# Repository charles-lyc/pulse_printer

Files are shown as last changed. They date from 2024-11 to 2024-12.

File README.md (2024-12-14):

# pulse_printer

## Introduce

2024 Maker Fair的小作品，放在SZDIY社区下面展出。观众可以将手指按压在指定位置十秒钟，即可得到机器为你量身打造的粗略心率曲线图，并且会有相应的小动物代表心率水平 ;-)

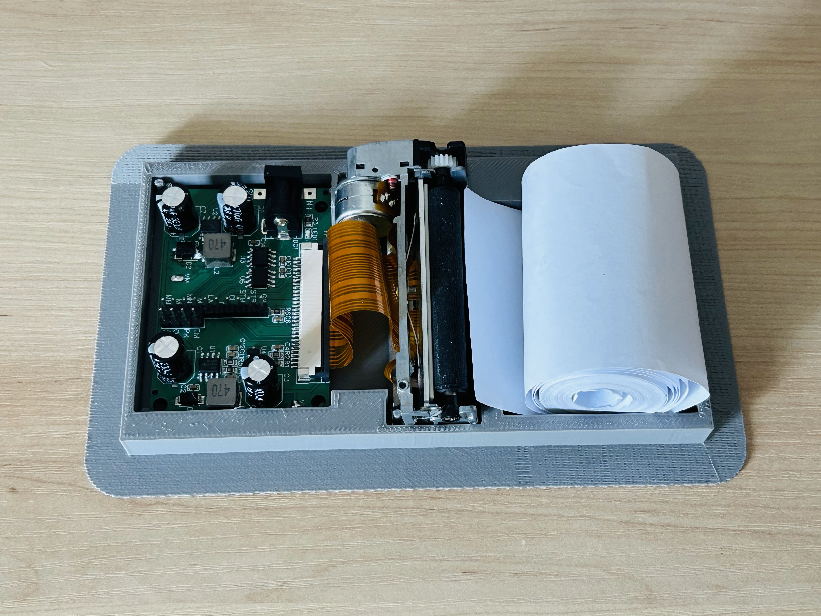
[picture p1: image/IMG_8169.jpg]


## Detail

* 获取心跳/脉搏信号：测量原理是检测血氧浓度（对不同波长光的吸收率不同）。可以使用**MAX30102**，我当时买错了将就用一下，ADC直出

* 热敏打印：打印纸局部加热后，发生化学反应（显色反应）

* 热敏打印的驱动：我在淘宝买的打印头和驱动板。驱动板主要就是电源，打印头里面应该是有个小芯片，原理类似于串转并芯片。打印过程其实就是逐行把像素点描黑或留白。为了一行打印，就需要利用DI、CLK和LAT锁存，将一行的像素缓存至打印机驱动小芯片里（输入一行结束，锁存拉高，等FLUSH完成，步进电机移动一行）。

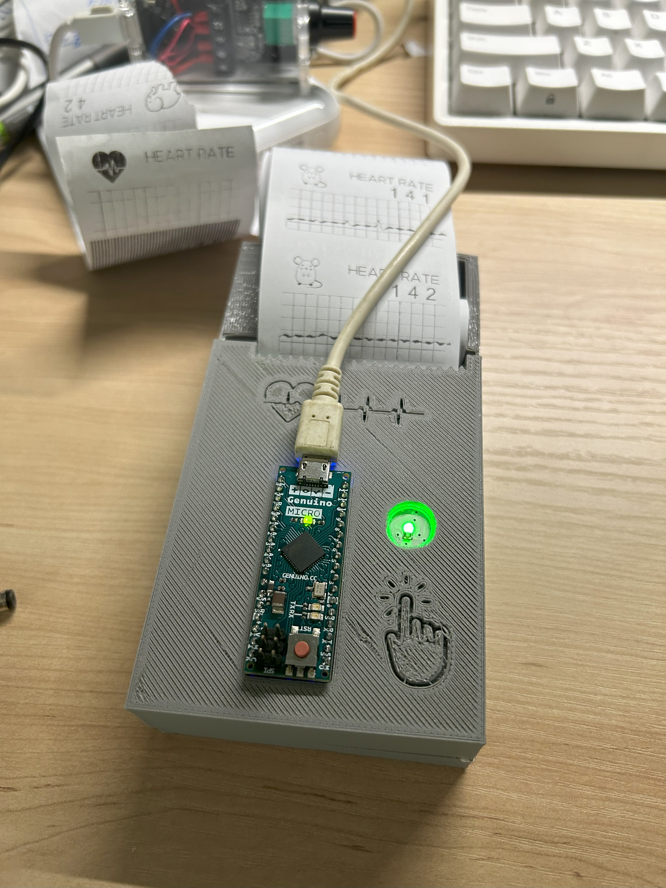
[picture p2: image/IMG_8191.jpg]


## TODO

* 控制脉搏传感器的电源，没有人按下时不要开（指纹底下应设计个按钮）

* 第二版还可以加入多人联机，然后测同步率，用一个彩屏来显示曲线相位...（但我估计懒得搞）

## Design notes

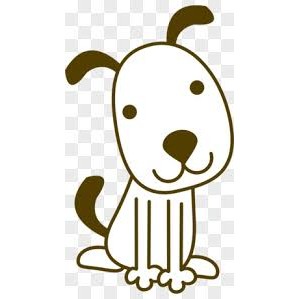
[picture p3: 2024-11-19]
misc/ui/d.jpg

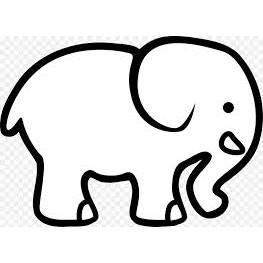
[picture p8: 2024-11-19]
misc/ui/e.jpg

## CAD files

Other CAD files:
shell/Pulse Printer v23.f3d

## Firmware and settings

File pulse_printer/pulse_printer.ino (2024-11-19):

#include "./HPD482.h"          //打印机头文件
#include "./img_background.h"  //待打印的图片数据
#include "./font.h"            //待打印的图片数据

#define BUFFER_SZ 1000
#define DISP_SZ 376
#define minADC 300
#define maxADC 800
#define WIDTH 384
#define HEIGHT 240
#define ANIM_X 16
#define ANIM_Y 8
#define DIGIT_X 0
#define DIGIT_Y 60
#define CURVE_X 8
#define CURVE_Y 105
HPD482 printer = HPD482();
const int btn_start_once = 22;
const int btn_empty = 18;
const int led = 13;
u8 hram[48], last_hram[48];
float alpha = 0.9;
u8 heart_rate_value[BUFFER_SZ];
bool start_once = false;
bool press_even = false;

// 统计大于均值线的独立区域的个数
int countPeaks(u8 *data, int size, int mean_line) {
  int peakCount = 0;
  int isAboveMean = 0;  // 标记是否在均值线以上
  u8 *pdata = (u8 *)data;

#if 0
	for (int i = 0; i < size; i++) {
		*pdata++ = *praw++;
	}
#endif
  // 遍历信号数组
  for (int i = 0; i < size; i++) {
    // 当前点高于均值线，且之前不在波峰中
    if (data[i] > mean_line && !isAboveMean) {
      isAboveMean = 1;
      peakCount++;  // 发现新的波峰，计数加1
    }
    // 当前点低于或等于均值线
    else if (data[i] <= mean_line) {
      isAboveMean = 0;  // 重置标记
    }
  }

  return peakCount;
}

void setup() {
  Serial.begin(9600);
  printer.Print_SetDeep(8);
  pinMode(btn_start_once, INPUT_PULLUP);
  pinMode(btn_empty, INPUT);
  pinMode(led, OUTPUT);
  randomSeed(analogRead(0));
}

void loop() {
BEGIN:
  int adcValue = 0;
  static int last_adcValue = 0;
  int bpm = 0;
  int mean = 0;
  long sum = 0;
  int region_count = 0;
  u8 *p_value;
  int count = 0;

  // 读取心率数据并处理
  memset(heart_rate_value, 0, sizeof(heart_rate_value));
  for (int i = 0; i < BUFFER_SZ; i++) {
    adcValue = analogRead(A5);
    // Serial.print(adcValue);
    // Serial.print(',');
    adcValue = alpha * adcValue + (1 - alpha) * last_adcValue;
    last_adcValue = adcValue;
    if (adcValue > maxADC) {
      adcValue = maxADC;
    }
    if (adcValue < minADC) {
      adcValue = minADC;
    }
    adcValue = (float)(adcValue - minADC) / (float)(maxADC - minADC) * 129.0f;

    // 等待第一个异常值作为开始，优信这款adc心率计在手指刚放上去时有明显的波动和异常值（糊弄）
    if (adcValue < 5) {
      Serial.println("press_even");
      press_even = true;
      digitalWrite(led, LOW);
      goto BEGIN;
    } else {
      if (press_even) {
        press_even = false;
        start_once = true;

        Serial.println("start_once");

        digitalWrite(led, HIGH);
        delay(50);
        digitalWrite(led, LOW);
        delay(50);
      }
      digitalWrite(led, HIGH);
    }

    // 环境也有数值
    if (!start_once) {
      goto BEGIN;
    }

    Serial.println(adcValue);
    heart_rate_value[i] = adcValue;
    delay(9);  // 孱弱的机能
  }
  start_once = false;

  Serial.println("Start process...");

  // 当按下达到8s，开始计算并打印心率和曲线
  for (int i = 0; i < BUFFER_SZ; i++) {
    sum += heart_rate_value[i];
  }
  mean = sum / BUFFER_SZ;
  mean += 8;
  Serial.println(mean);
  region_count = countPeaks(heart_rate_value, BUFFER_SZ, mean);
  Serial.println(region_count);
  bpm = region_count * 60.0 / (BUFFER_SZ / 100);
  Serial.println(bpm);
  if (bpm < 45) {
    bpm = 45;
  }
  if (bpm > 180) {
    bpm = 180;
  }
  if (bpm == 45 || bpm == 180) {
    Serial.println("Ramdon");
    bpm = random(50, 160);
    Serial.println(bpm);
  }

  // 将所有需要打印的图片都缓存到hram中，一行行计算
  memset(last_hram, 0x00, sizeof(hram));
  for (int row = 0; row < HEIGHT; row++) {
    memset(hram, 0x00, sizeof(hram));

    // 背景
    for (int i = 0; i < sizeof(hram); i++) {
      hram[i] = pgm_read_byte(&gPic_background[row * (WIDTH / 8) + i]);
    }

    // 动物标志
    const unsigned char *p = gPic_dog;
    if (row >= ANIM_Y && row < ANIM_Y + 96) {
      int line = (row - ANIM_Y);
      if (bpm < 60) {
        p = gPic_Elephant;
      } else if (bpm < 110) {
        p = gPic_dog;
      } else {
        p = gPic_mouse;
      }
      for (int i = 0; i < 96 / 8; i++) {
        hram[ANIM_X / 8 + i] = pgm_read_byte(&p[line * (96 / 8) + i]);
      }
    }

    // // 数字
    if (row >= DIGIT_Y && row < DIGIT_Y + 40) {
      u8 digit_1 = bpm / 100;
      u8 digit_2 = (bpm % 100) / 10;
      u8 digit_3 = bpm % 10;
      for (int i = 0; i < sizeof(hram); i++) {
        for (int i = 0; i < 40 / 8; i++) {
          if (digit_1 != 0) {
            hram[30 + (40 / 8) * 0 + i] = pgm_read_byte(&ascii_pic4040[digit_1][(row - DIGIT_Y) * (40 / 8) + i]);
          }
          hram[30 + (40 / 8) * 1 + i] = pgm_read_byte(&ascii_pic4040[digit_2][(row - DIGIT_Y) * (40 / 8) + i]);
          hram[30 + (40 / 8) * 2 + i] = pgm_read_byte(&ascii_pic4040[digit_3][(row - DIGIT_Y) * (40 / 8) + i]);
        }
      }
    }

    // 曲线
    if (row >= CURVE_Y && row < CURVE_Y + 130) {
      int line = (129 - (row - CURVE_Y));
      // Serial.print(line);

      // 简易加粗（复制上一次）
      for (int i = 0; i < 48; i++) {
        // hram[i] |= last_hram[i];
      }
      memset(last_hram, 0x00, sizeof(hram));

      // 遍历心率数据，只要两点间连线出现在当前行就应标记为1
      for (int t = 1; t < DISP_SZ; t++) {
        p_value = heart_rate_value;
        // i等于当前像素，标记hram为1
        // i-1的值小于当前hram的行位置像素，i大于等于当前像素，标记hram为1
        // i-1的值大于当前hram的行位置像素，i小于等于当前像素，标记hram为1
        if ((p_value[t] == line) || (p_value[t - 1] < line && p_value[t] > line) || (p_value[t - 1] > line && p_value[t] < line)) {
          hram[(CURVE_X / 8) + (t / 8)] |= 0x01 << (7 - t % 8);
          last_hram[(CURVE_X / 8) + (t / 8)] |= 0x01 << (7 - t % 8);
        }
      }
    }

    // 逐行绘画
    printer.Print_Picture(0, hram, WIDTH, 1, 0);
  }

  printer.Motor_Run(70, 0);
  printer.Print_Stop();
}

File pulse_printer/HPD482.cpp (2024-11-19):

/*
HPD482驱动程序v3.6 for Arduino UNO
///////////////////////////////////////////////////////////////////////////////////////////////
作者：有立diy
淘宝店铺：有立diy
淘宝链接：https://shop587795831.taobao.com/
原创声明：本例程为热敏打印机模块HPD482配套例程，仅供参考，不得用于商业等用途，其他后果概不负责。
		  如需使用，注明出处。
///////////////////////////////////////////////////////////////////////////////////////////////
*/
#include "HPD482.h"
#include "font.h"

//打印机微秒延时
void HPD482::pdelay_us(u16 tus)
{
	delayMicroseconds(tus);
}
//打印机毫秒延时
void HPD482::pdelay_ms(u16 tms)
{
	if(tms==0);
	else delay(tms);
}
//***********************************************************************
//步进电机正转一个序列
#define MOTOR_STEPF		switch((motor_step_i++)%4)\
						{\
							case 0:MOTOR_STEP1;break;\
							case 1:MOTOR_STEP2;break;\
							case 2:MOTOR_STEP3;break;\
							case 3:MOTOR_STEP4;break;\
						}
//步进电机反转一个序列
#define MOTOR_STEPNF 	switch((motor_step_i++)%4)\
						{\
							case 0:MOTOR_STEP4;break;\
							case 1:MOTOR_STEP3;break;\
							case 2:MOTOR_STEP2;break;\
							case 3:MOTOR_STEP1;break;\
						}

/*
步进电机驱动函数
输入参数：
	cont:旋转次数（转一次进纸0.125mm），范围：[1,255]
	dir:方向（0：正转；1：反转）
*/
void HPD482::Motor_Run(u8 cont,u8 dir)
{
	static u8 motor_dir_x=0;
	if(motor_dir_x!=dir)//方向翻转
	{
		if(motor_step_i%2==0)motor_step_i+=2;
		motor_dir_x=dir;//存储此次方向
	}
	if(dir==0)//正转
	{
		while(cont--)
		{
			MOTOR_STEPF;pdelay_us(Motorspeed+ALIGN_DELAY);
			pdelay_ms(SLOW_DELAY);
			MOTOR_STEPF;pdelay_us(Motorspeed+ALIGN_DELAY);
			pdelay_ms(SLOW_DELAY);
		}
	}
	else//反转
	{
		while(cont--)
		{
			MOTOR_STEPNF;pdelay_us(Motorspeed+ALIGN_DELAY);
			pdelay_ms(SLOW_DELAY);
			MOTOR_STEPNF;pdelay_us(Motorspeed+ALIGN_DELAY);
			pdelay_ms(SLOW_DELAY);
		}
	}
	MOTOR_STOP;//停转
}

/*
步进电机退纸
输入参数：
	dot：退纸点数,范围：[1,65025]
*/
void HPD482::Motor_Back(u16 dot)
{
	u8 mtim,ddot;
	if(dot>255)
	{
		mtim=dot/255;
		ddot=dot%255;
		while(mtim--)Motor_Run(255,1);
	}
	else ddot=dot;
	Motor_Run(ddot+7,1);
	Motor_Run(7,0);//排除行程误差
}

/*
设置打印颜色深度
输入参数：
	deepcolor：打印深度，范围为0-100的整数
注：数值越大打印颜色越深，打印速度越慢，同时越容易因高温损坏打印模块！因此数值不宜太大。
*/
void HPD482::Print_SetDeep(u8 deepcolor=0)
{
	if(deepcolor>100)deepcolor=100;
	Ptdeepcolor=deepcolor*50;
	Motorspeed=(2*(HT_minhttim+Ptdeepcolor)+Leftdeep);
	if(Motorspeed<2000)Motorspeed=2000;
}

/*
设置左半部分打印颜色深度
*/
void HPD482::Print_SetLfDeep(u8 Leftdeepcolor=0)
{
	Leftdeep=Leftdeepcolor*10;
	Motorspeed=(2*(HT_minhttim+Ptdeepcolor)+Leftdeep);
	if(Motorspeed<2000)Motorspeed=2000;
}

/*
停止打印
*/
void HPD482::Print_Stop()
{
	HEAT_STOP;
	MOTOR_STOP;
}

/*
打印机初始化
*/
HPD482::HPD482(void)
{
	pinMode(MNB_pin,OUTPUT);
	pinMode(STBB_pin,OUTPUT);
	pinMode(STBA_pin,OUTPUT);
	HEAT_STOP;
	pinMode(MB_pin,OUTPUT);
	pinMode(MNA_pin,OUTPUT);
	pinMode(MA_pin,OUTPUT);
	MOTOR_STOP;
	pinMode(LAT_pin,OUTPUT);
	pinMode(DI_pin,OUTPUT);
	pinMode(CLK_pin,OUTPUT);
	Print_SetLfDeep(10);
	Print_SetDeep(10);//设置打印深度
}

/*
发送一字节数据
输入参数：
	onebytedata:一字节数据
返回参数：脉冲个数，即要加热的点的个数
*/
u8 HPD482::Send_OneByte(u8 onebytedata)
{
	u8 i,htnum=0;
	for(i=0;i<8;i++)
	{
		CLK(LOW);
		if(onebytedata&0x80){DI(HIGH);htnum++;}
		else DI(LOW);
		CLK(HIGH);
		onebytedata<<=1;
	}
	CLK(LOW);
	return htnum;
}

/*
控制加热
输入参数：
	tim:加热时间，单位：us
	ctr:加热控制线。1：STBA加热；2：STBB加热
*/
void HPD482::Print_Control(u16 tim,u8 ctr)
{
	switch(ctr)
	{
		case 1:STBA(HIGH);pdelay_us(tim+Leftdeep+Ptdeepcolor);STBA(LOW);break;
		case 2:STBB(HIGH);pdelay_us(tim+Ptdeepcolor);STBB(LOW);break;
	}
}

/*
打印一行像素点阵
输入参数：
	pixlindat:48字节数据
*/
void HPD482::Print_OneLine(u8 *pixlindat)
{
	u8 i,k,cont;
	u16 a[2];
	for(k=0;k<2;k++)
	{
		cont=0;
		for(i=0;i<24;i++)cont+=Send_OneByte(*(pixlindat++));//查待加热的点数
		if(cont<HT_mindots)a[k]=HT_minhttim;//加热时间下限，保证每个点都能打印上
		else if(cont>HT_maxdots)a[k]=HT_maxhttim;//加热时间上限
		else a[k]=cont*HT_kdottim+HT_bdottim;//平均加热时间
	}
	LAT(HIGH);
	LAT(LOW);//拉低锁存端
	pdelay_us(3);
	LAT(HIGH);
	Print_Control(a[0],1);//加热前半部分
	Print_Control(a[1],2);//加热后半部分
	HEAT_STOP;//停止加热
}

/*
打印虚线
输入参数：
	linesnum:打印几条虚线
	dist:线间距，单位：mm，最大值31
*/
void HPD482::Print_Lines(u8 linesnum,u8 dist)
{
	u8 aa[48],i;
	for(i=0;i<48;)
	{
		aa[i++]=0xFF;
		aa[i++]=0x00;
	}
	while(linesnum--)
	{
		i=8*dist;
		MOTOR_STEPF;
		pdelay_ms(SLOW_DELAY);
		Print_OneLine(aa);
		MOTOR_STEPF;pdelay_us(Motorspeed+ALIGN_DELAY);
		pdelay_ms(SLOW_DELAY);
		while(--i)
		{
			MOTOR_STEPF;pdelay_us(Motorspeed+ALIGN_DELAY);
			pdelay_ms(SLOW_DELAY);
			MOTOR_STEPF;pdelay_us(Motorspeed+ALIGN_DELAY);
			pdelay_ms(SLOW_DELAY);
		}
	}
	Print_Stop();
}

#if IS_PRINT_PICT
/*
打印黑白单色图片
图片应为按行取模
输入参数：
	startx:打印起始位置，取值范围为0到47的整数
	picdata:纯图片数据
	widthpix:图片像素宽度，宽度应<=384，>384的部分将被舍弃
	heightpix:图片像素高度，最大65536
	InEx:是否打印内部存储图片，0：否，1：是
*/
void HPD482::Print_Picture(u8 startx,u8 *picdata,u16 widthpix,u16 heightpix,u8 InEx)
{
	u16 iline;//列变量
	u16 pixlin;//行变量
	u8 widthbyte,ptbyte;//宽度字节/实际打印字节
	u8 onepixline[48];//存放一行像素数据

	widthbyte=widthpix/8+(widthpix%8?1:0);//计算图片宽多少字节
	if(startx>47)startx=47;
	if((startx+widthbyte)>48)ptbyte=48-startx;//如果宽度超过48字节，将图片裁剪到48字节
	else ptbyte=widthbyte;

	for(pixlin=0;pixlin<heightpix;pixlin++)//行扫描并打印一行
	{
		//走一步长
		MOTOR_STEPF;pdelay_us(Motorspeed+ALIGN_DELAY);
		pdelay_ms(SLOW_DELAY);
		MOTOR_STEPF;
		pdelay_ms(SLOW_DELAY);

		for(iline=0;iline<startx;iline++)onepixline[iline]=0x00;//存入空数据
		for(iline=0;iline<ptbyte;iline++)
		{
			if(InEx)onepixline[iline+startx]=pgm_read_byte(picdata++);
			else onepixline[iline+startx]=*(picdata++);
		}
		if(ptbyte!=widthbyte)picdata+=(startx+widthbyte-48);//跳过裁剪掉的部分
		else for(iline=0;iline<48-startx-ptbyte;iline++)onepixline[iline+startx+ptbyte]=0x00;//存入空数据

		Print_OneLine(onepixline);
	}
}
/*
打印使用Img2Lcd软件取模的图片
Img2Lcd软件图片取模方式：输出数组+水平扫描+单色+包含图像头数据+高位在前
图像头数据格式（共6字节）：扫描方式，灰度值，图片宽（高8位），图片宽（低8位），图片高（高8位），图片高（低8位）
输入参数：
	x:打印起始位置，取值范围为0到47的整数
	pic:图片数据
	InEx:是否打印内部存储图片，0：否，1：是
*/
void HPD482::Print_Img2Lcd(u8 x,u8 *pic,u8 InEx)
{
	u16 width,height;//图片像素宽高
	u8 *imag;

	if(InEx)//打印UNO内部图片
	{
		imag=pic+6;//跳过头数据的图片数组下标
		width=(pgm_read_byte(pic+2)<<8)+pgm_read_byte(pic+3);//根据头数据计算图片宽度
		height=(pgm_read_byte(pic+4)<<8)+pgm_read_byte(pic+5);//根据头数据计算图片高度
		Print_Picture(x,imag,width,height,1);
	}
	else//打印内存里的图片
	{
		imag=pic+6;//跳过头数据的图片数组下标
		width=(*(pic+2)<<8)+*(pic+3);//根据头数据计算图片宽度
		height=(*(pic+4)<<8)+*(pic+5);//根据头数据计算图片高度
		Print_Picture(x,imag,width,height,0);
	}
	
	Print_Stop();
}
#endif
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

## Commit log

2024-11-19 首次提交，有基本功能
    [Pulse Printer v23.f3d, raw.csv]
2024-11-19 更改RM
    [raw.csv]
